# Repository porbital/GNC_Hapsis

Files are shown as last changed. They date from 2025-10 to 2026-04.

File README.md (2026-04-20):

# GNC_Hapsis

Software and hardware for GNC Hapsis.

    If you have any questions, please reach out to Matthew Allen on Slack.

## STAG Software 

The C++ code is stored in `STAG/flight_controller_v3`.

This was developed using PlatformIO, but can be used with Arduino IDE as well.

The current software is complete and will be used on the STAG mission. 

Hardware-in-the-loop is possible with this code setup, and can be enabled by commenting out the flag in `config.h`

## STAG PCB

The PCB for this project (version 4.1) is stored under `polaris4.1/`.

The current PCB is fully complete. I assembled it without a stencil, using solder paste and a hot plate. (In the future, it is worth buying a stencil).

### AI Transparency Statement

As I'm sure you all are aware, AI is an incredibly powerful tool. However, I think that it is important to be honest and clear regarding how it is utilized in a project, especially one of this nature.

AI was used for debugging, research, and some code generation (primarily autocomplete and boilerplate code). It also generated the flight visualization script.

# Go Orbital!

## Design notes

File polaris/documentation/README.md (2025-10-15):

# Purdue Orbital GNC -- Polaris Program Documentation

## Overview
This program controls the attitude of a launch structure using thrusters and an inertial measurement unit (IMU) sensor BNO055. It implements a PID control loop to maintain a desired heading (orientation) and logs telemetry data to an SD card. The program also manages status LEDs and thruster actuation using digital I/O pins.

---

## Hardware Inputs and Pinout

| Name | Pin | Description |
|---|---|---|
| SCL | IMU SCL | I2C clock line for BNO055 IMU |
| SDA | IMU SDA | I2C data line for BNO055 IMU |
| 3.3V | VIN on IMU | Power supply for the IMU |
| D5 | GPIO D5 | Yellow LED (flashes during countdown) |
| D6 | GPIO D6 | Green LED (blinks while running) |
| D9 | GPIO D9 | Red LED (blinks on error/failure) |
| D10 | Thruster L | Left thruster control (not currently used) |
| D11 | Thruster R | Right thruster control (not currently used) |
| D12 | Thruster 3 | Thruster control (connected to positive thruster) |
| D13 | Thruster 4 | Thruster control (connected to negative thruster) |
| GND | Ground | Common ground for LEDs, IMU, and MOSFETs |
| SD Card CS | board.SD_CS| Chip select pin for SD card SPI interface |
| SD Card CLK | board.SD_CLK| SPI clock for SD card |
| SD Card MOSI | board.SD_MOSI| SPI MOSI for SD card |
| SD Card MISO | board.SD_MISO| SPI MISO for SD card |

## Main Power Architecture

The power system starts with a 14.8V battery, which is stepped down to 12V via a buck converter. Each MOSFET board receives switched 12V power and output signals to individual solenoid valves, enabling safe control of thrusters. This modular design allows independent activation of thrusters and easy troubleshooting.

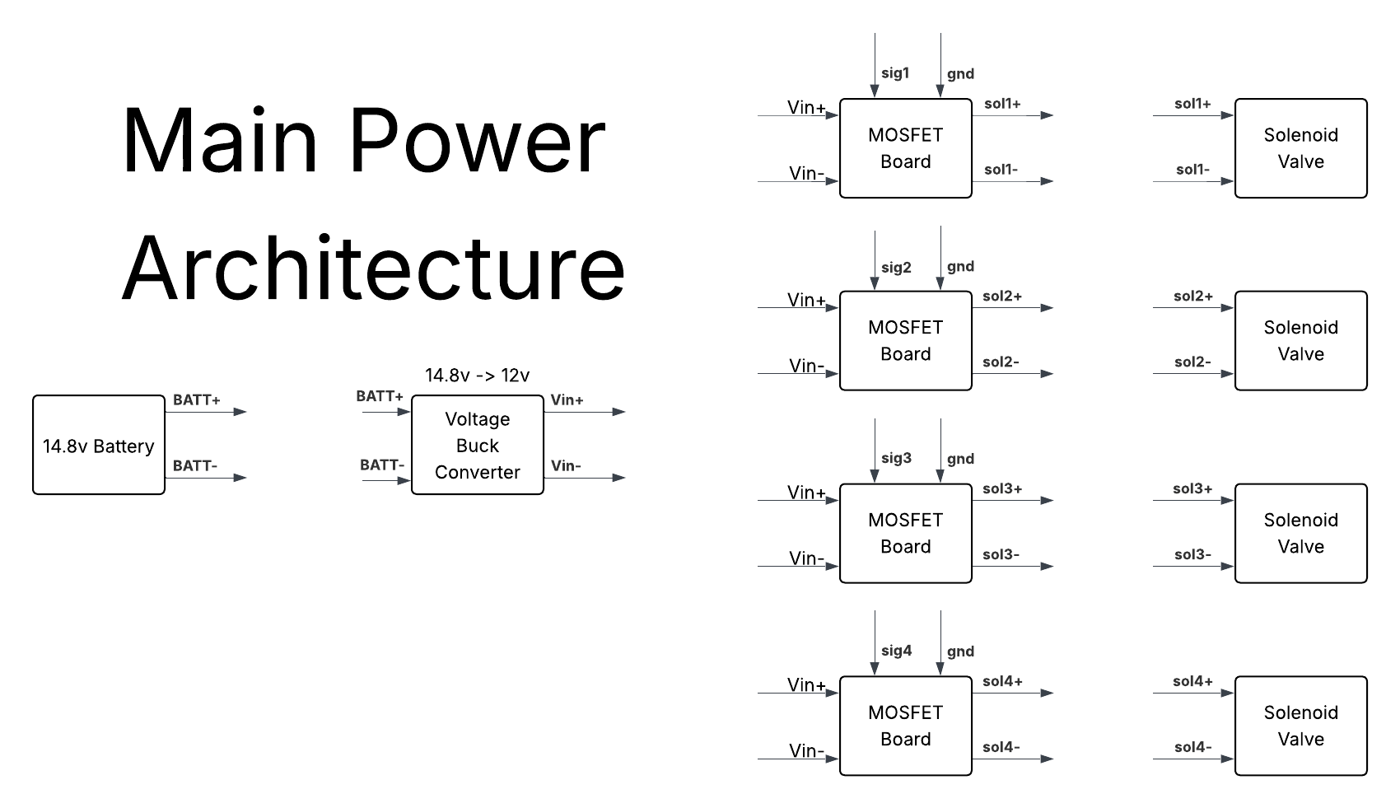
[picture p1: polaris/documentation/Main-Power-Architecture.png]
Main Power Architecture

---

## Flight Software Wiring

This schematic shows how the IMU (BNO055) connects via I2C (SCL, SDA, 3.3V, GND) to the Raspberry Pi RP2040 microcontroller. The RP2040 directs LED status signals and outputs digital thruster control pins (sig1–sig4) to the MOSFET boards, interfacing each with its corresponding solenoid valve. Separate or buck-converted power ensures safe operation of logic and actuators.
:w

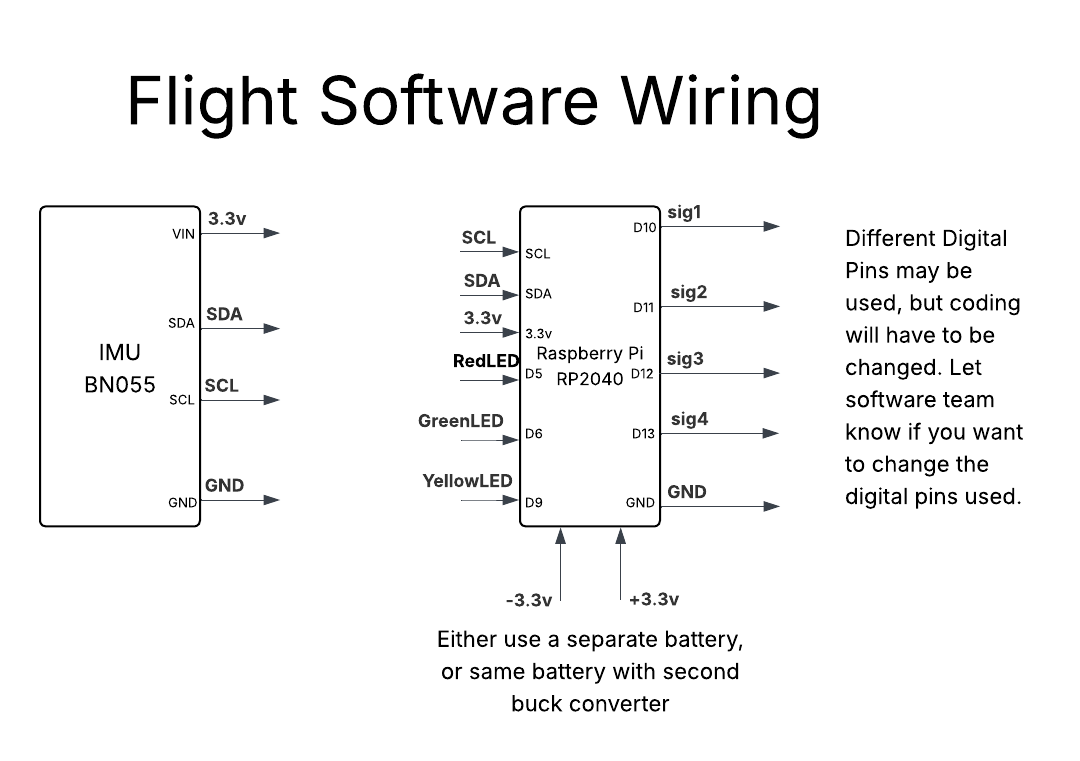
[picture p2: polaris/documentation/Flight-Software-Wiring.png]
Flight Software Wiring


---
**Thruster Notes:**
- Thruster 1 and 3 impart negative torque on the structure.
- Thruster 2 and 4 impart positive torque.
- Current thruster firing only uses left/right thrusters (D12 and D13 pins).
- Thrusters are controlled through MOSFETs connected to these GPIO pins.

---

## Functions

### `temperature()`
Reads and filters the temperature from the BNO055 IMU sensor. Checks for a specific error condition with the sensor and returns a corrected temperature value.

### `get_current_heading()`
Reads the current heading in degrees from the IMU sensor's Euler angle output.

---

## How It Works

### Initialization
- LEDs and thruster control pins are initialized as digital outputs.
- The program performs a 5-step countdown indicated by flashing the yellow LED.
- The SD card is initialized and a new CSV log file is created with a timestamped filename.
- I2C communication is started with the BNO055 IMU sensor.
- Status variables and PID constants are set up.

### Main Control Loop
- The program continuously reads the current heading from the IMU.
- It calculates the error between the desired heading (setpoint = 0°, North) and the current heading, accounting for angle wraparound (handling 0° = 360°).
- Time elapsed between loop iterations is calculated for derivative computations.
- A low-pass filter smooths the derivative of error to reduce noise.
- PID output is computed using proportional (Kp) and derivative (Kd) gains.
- Based on PID output, one of two thrusters is fired to correct the heading:
  - Positive output fires the negative thruster (right)
  - Negative output fires the positive thruster (left)
- A deadzone threshold prevents thrusters from firing for small errors near zero.
- The green LED blinks continuously to indicate the system is active.
- Telemetry data including time delta, angular position, thruster states, gyro data, and PID values are logged to the SD card.
- Errors during operation cause the red LED to blink indefinitely and print error messages.

### PID Control Details
- Proportional gain \(K_p = 0.56\) and derivative gain \(K_d = 0.45\) are tuned constants for controlling the thrusters.
- The derivative is filtered using a low-pass filter with time constant \(\tau = 0.1\) to reduce sensor noise effects.
- Error is calculated with wrap-around so the heading difference is always within \([-180°, 180°]\).

---

## Status LEDs

| LED Color | Pin | Function |
|---|-----|---|
| Red | D9  | Indicates failure/error |
| Green | D6  | Blinks to show the program is running |
| Yellow | D5  | Flashes during countdown before start |

---

## Summary
This software manages an attitude control system with:

- An IMU sensor to read orientation.
- A PID controller to maintain a set heading.
- Thrusters activated through MOSFETs to apply torque.
- Status LEDs to provide feedback on system state.
- Data logging of sensor and control data to an SD card for post-flight analysis.

The implementation focuses on error handling and stable control through filtering and set thresholds in a resource-constrained embedded environment.

---

*Documentation generated for the Purdue Orbital GNC Polaris Program by Adafruit Industries under MIT License.*

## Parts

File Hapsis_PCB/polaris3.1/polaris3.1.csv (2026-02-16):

Id | Designator | Footprint | Quantity | Designation | Supplier and ref
1 | R13 | R_0603_1608Metric | 1 | 10k
2 | Q3,Q2,Q1,Q4 | TO-220-3_Horizontal_TabDown | 4 | IRLB8721PBF
3 | R1,R7,R4,R8 | R_1206_3216Metric | 4 | 150
4 | C6,C4 | C_0805_2012Metric | 2 | 22uF
5 | J4,J3,J2,J5 | TerminalBlock_RND_205-00276_1x02_P5.00mm_Vertical | 4 | Screw_Terminal_01x02
6 | R5,R3,R6,R2 | R_1206_3216Metric | 4 | 10k
7 | U2 | SOT-23-6 | 1 | TPS56339DDC
8 | D4,D5,D1,D3 | D_DO-41_SOD81_P10.16mm_Horizontal | 4 | 1N4007
9 | R14 | R_0603_1608Metric | 1 | 30
10 | CAN TX | PinHeader_1x07_P2.54mm_Vertical | 1 | CAN
11 | D6,D7 | LED_1210_3225Metric | 2 | LED
12 | L1 | L_Bourns_SRP1038C_10.0x10.0mm | 1 | 10uH
13 | R10,R9 | R_1206_3216Metric | 2 | 1.8k
14 | J7 | TerminalBlock_Phoenix_MKDS-1,5-2_1x02_P5.00mm_Horizontal | 1 | Screw_Terminal_01x02
15 | BNO055 IMU | PinHeader_1x06_P2.54mm_Vertical | 1 | Conn_01x06_Socket
16 | C3,C5 | C_0805_2012Metric | 2 | 100nF
17 | C1,C2 | C_0805_2012Metric | 2 | 10uF
18 | R12 | R_0603_1608Metric | 1 | 140k
19 | A1 | Arduino_Nano | 1 | Arduino_Nano_ESP32

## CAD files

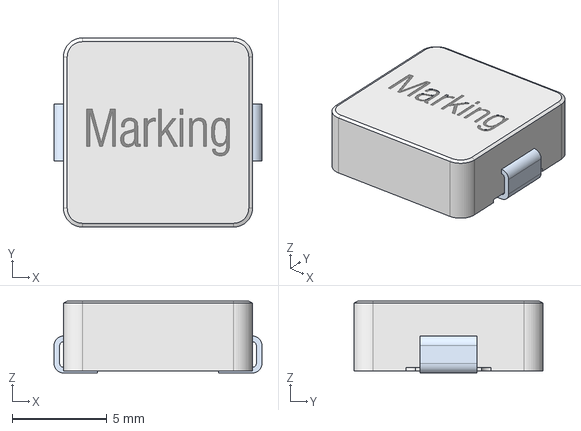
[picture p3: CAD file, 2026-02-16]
Hapsis_PCB/polaris3.1/vendor_files/WE-LHMI_1040+(rev1).stp
11.0 x 10.0 x 3.80 mm

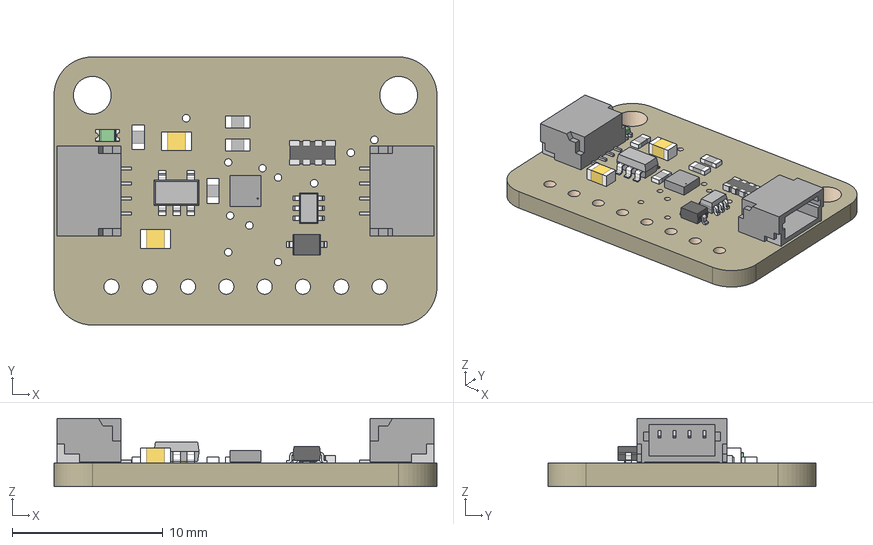
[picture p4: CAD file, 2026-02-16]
Hapsis_PCB/polaris4.1/vendor_files/4816 BMP390 QT.step
25.4 x 17.8 x 4.53 mm
Board
10K x 4
1N4148
BMP388
10uF x 2
AP2112K-3.3
10K_1
BSS138
STEMMA_I2C_QT x 2
GREEN

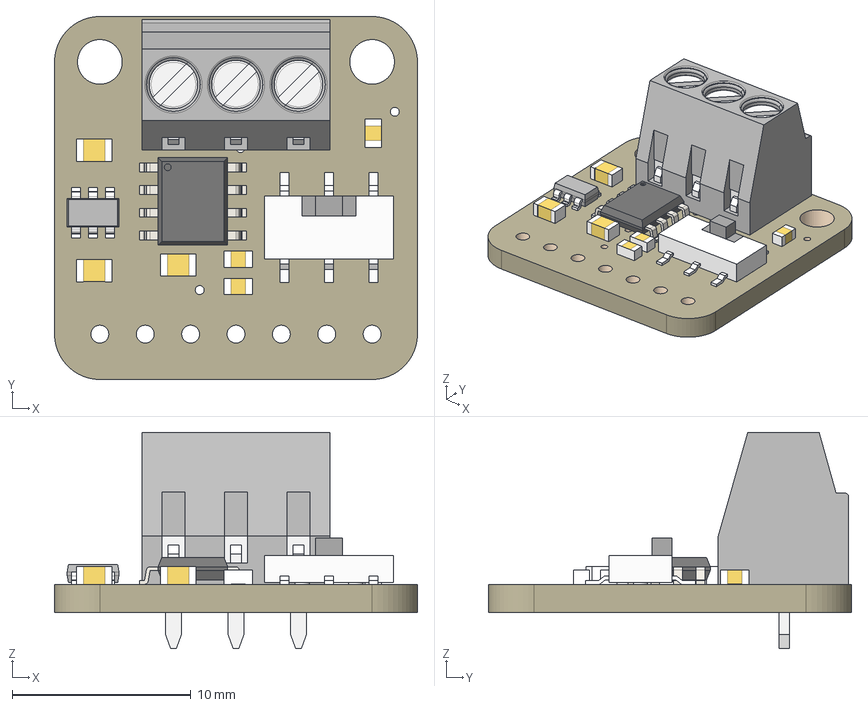
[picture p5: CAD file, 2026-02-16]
Hapsis_PCB/polaris3.1/vendor_files/5708 CAN Pal.step
20.3 x 20.3 x 12.1 mm
Board
TJA1051T/3
3.5mm Terminal
10uF x 2
AP3602
1uF
60 ohm x 3
EG1390

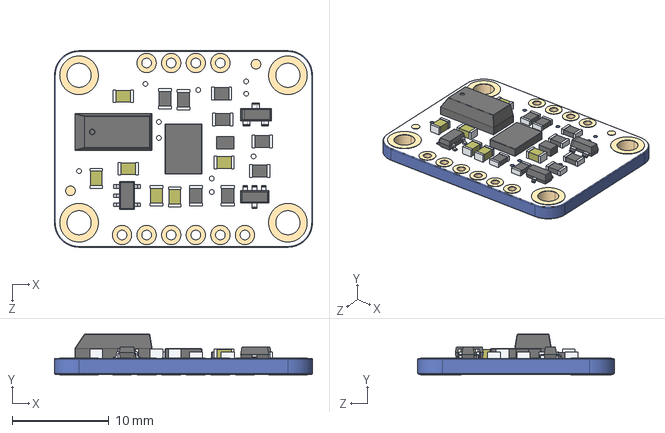
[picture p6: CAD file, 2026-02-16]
Hapsis_PCB/polaris4.1/vendor_files/Adafruit_BNO055_AP214.STEP
26.7 x 4.20 x 20.3 mm

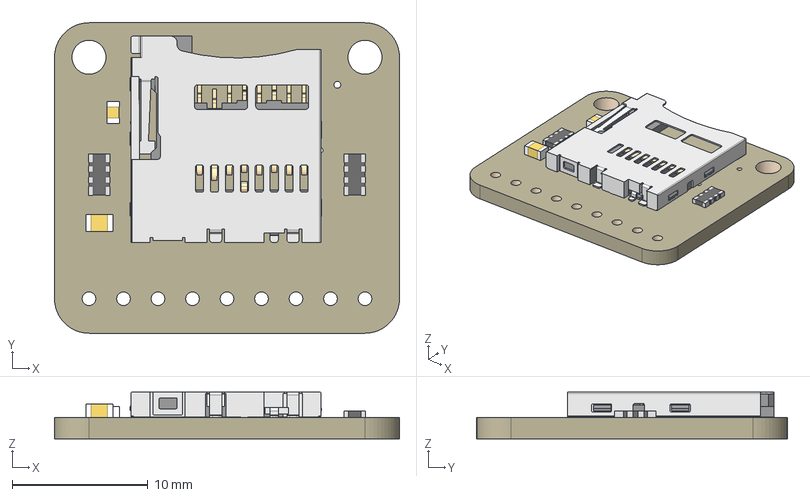
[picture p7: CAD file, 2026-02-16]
Hapsis_PCB/polaris3.1/vendor_files/4682 Micro SD Breakout.step
25.4 x 22.9 x 3.45 mm
Board
microSD
10uF
0.1uF
47K x 2

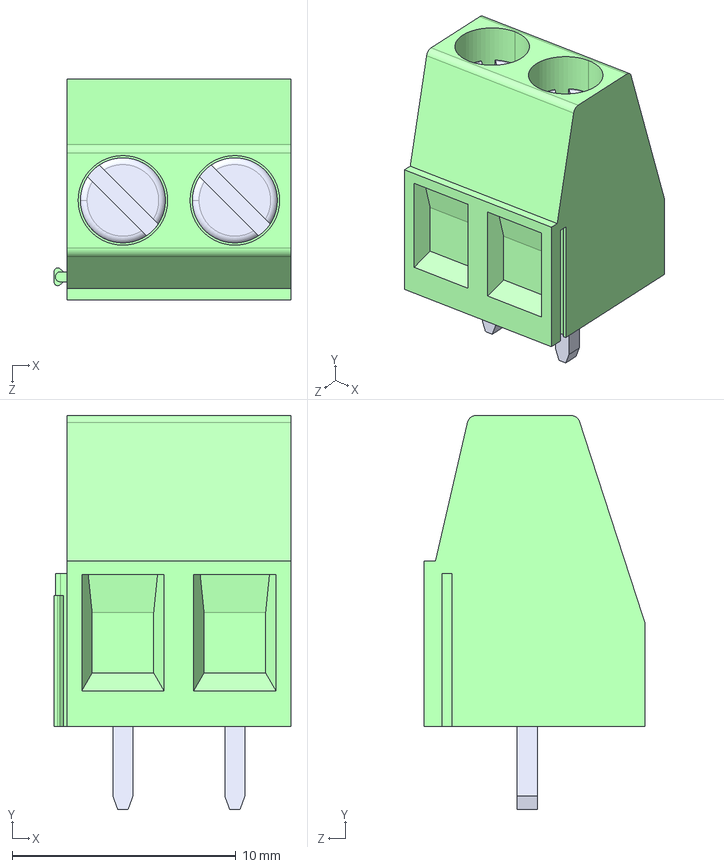
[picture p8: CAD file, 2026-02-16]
Hapsis_PCB/polaris3.1/vendor_files/SCREW_TERMINAL.STEP
10.6 x 17.6 x 9.85 mm
Pin^1715xxx x 2
Screw^1715xxx x 2

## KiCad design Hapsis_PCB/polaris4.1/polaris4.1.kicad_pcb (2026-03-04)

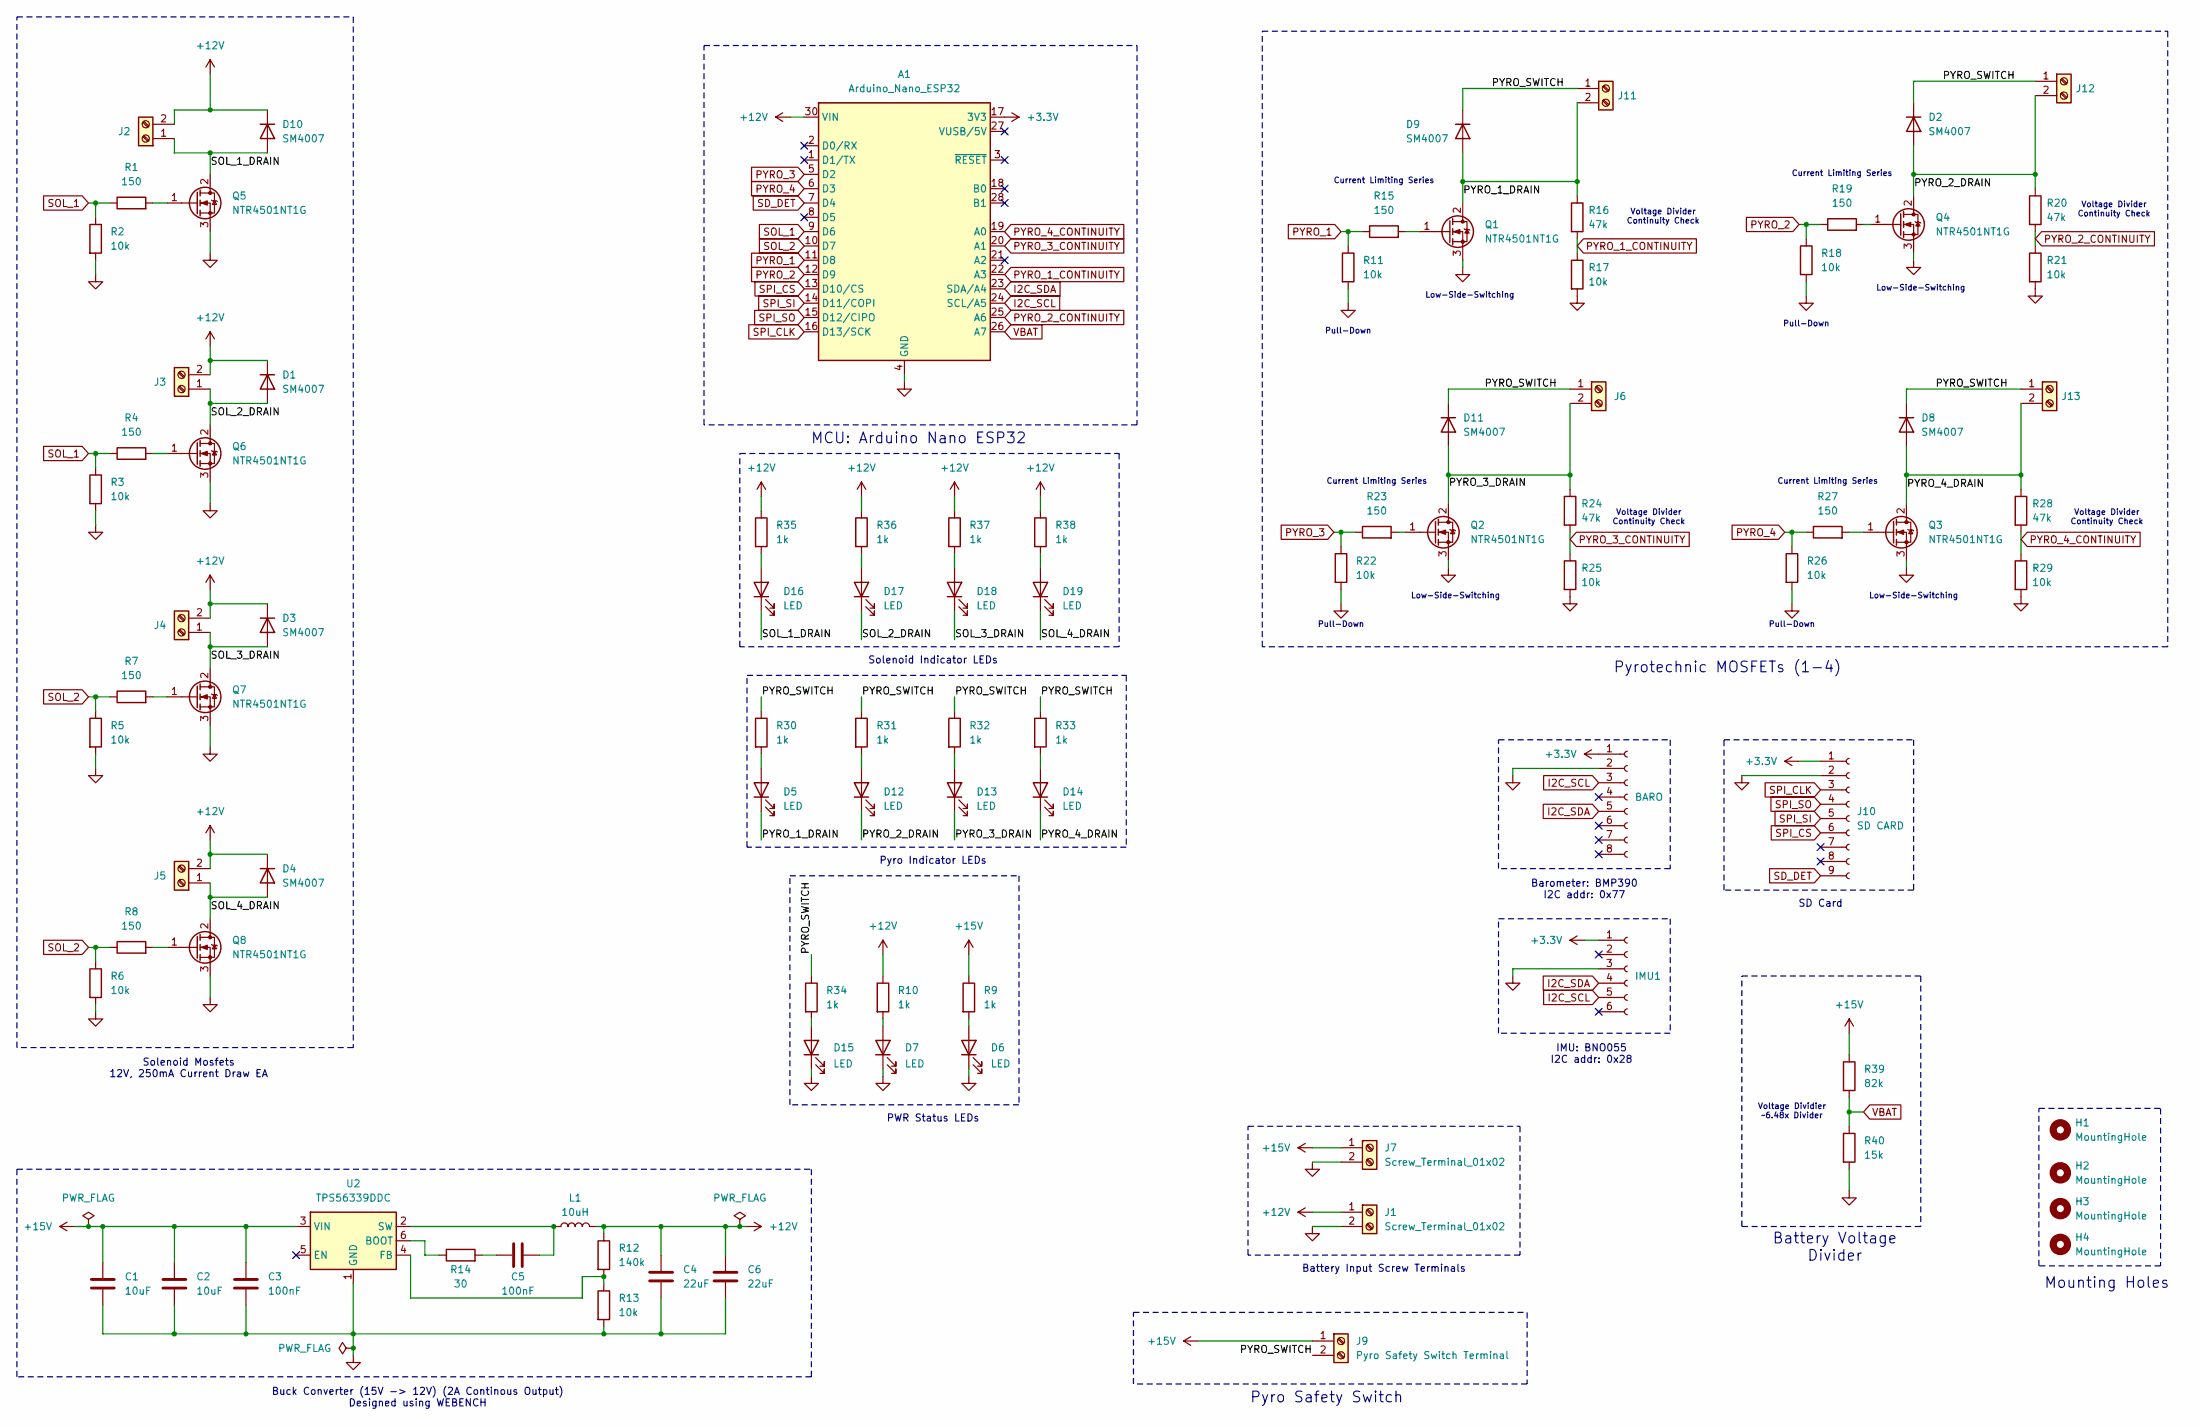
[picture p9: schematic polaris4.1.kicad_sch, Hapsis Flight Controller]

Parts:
A1: Arduino_Nano_ESP32; Arduino_Nano
C1, C2: 10uF; C_0805_2012Metric
C3, C5: 100nF; C_0805_2012Metric
C4, C6: 22uF; C_0805_2012Metric
D1, D2, D3, D4, D8, D9, D10, D11: SM4007; D_MELF
D5, D6, D7, D12, D13, D14, D15, D16, D17, D18, D19: LED; LED_0603_1608Metric
H1, H2, H3, H4: MountingHole; MountingHole_3mm
IMU1: Conn_01x06_Socket; PinHeader_1x06_P2.54mm_Vertical
J1, J7: Screw_Terminal_01x02; TerminalBlock_Phoenix_MKDS-1,5-2_1x02_P5.00mm_Horizontal
J2, J3, J4, J5, J6, J11, J12, J13: Screw_Terminal_01x02; TerminalBlock_RND_205-00276_1x02_P5.00mm_Vertical
J8: BARO; PinHeader_1x08_P2.54mm_Vertical
J9: Pyro Safety Switch Terminal; TerminalBlock_Phoenix_MKDS-1,5-2_1x02_P5.00mm_Horizontal
J10: SD CARD; PinHeader_1x09_P2.54mm_Vertical
L1: 10uH; L_Bourns_SRP1038C_10.0x10.0mm
Q1, Q2, Q3, Q4, Q5, Q6, Q7, Q8: NTR4501NT1G; SOT-23-3
R1, R4, R7, R8, R15, R19, R23, R27: 150; R_0805_2012Metric
R2, R3, R5, R6, R11, R17, R18, R21, R22, R25, R26, R29: 10k; R_0805_2012Metric
R9, R10, R30, R31, R32, R33, R34, R35, R36, R37, R38: 1k; R_0805_2012Metric
R12: 140k; R_0603_1608Metric
R13: 10k; R_0603_1608Metric
R14: 30; R_0603_1608Metric
R16, R20, R24, R28: 47k; R_0805_2012Metric
R39: 82k; R_0805_2012Metric
R40: 15k; R_0805_2012Metric
U2: TPS56339DDC; SOT-23-6

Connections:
+3.3V: A1.17 (3V3), IMU1.1, J8.1, J10.1
+12V: A1.30 (VIN), C4.1, C6.1, D1.1 (K), D3.1 (K), D4.1 (K), D10.1 (K), J1.1, J2.2, J3.2, J4.2, J5.2, L1.2, R10.1, R12.1, R35.1, R36.1, R37.1, R38.1
+15V: C1.1, C2.1, C3.1, J7.1, J9.1, R9.1, R39.1, U2.3 (VIN)
/PYRO_1_DRAIN: D5.1 (K), D9.2 (A), J11.2, Q1.2 (D), R16.1
/PYRO_2_DRAIN: D2.2 (A), D12.1 (K), J12.2, Q4.2 (D), R20.1
/PYRO_3_DRAIN: D11.2 (A), D13.1 (K), J6.2, Q2.2 (D), R24.1
/PYRO_4_DRAIN: D8.2 (A), D14.1 (K), J13.2, Q3.2 (D), R28.1
/PYRO_SWITCH: D2.1 (K), D8.1 (K), D9.1 (K), D11.1 (K), J6.1, J9.2, J11.1, J12.1, J13.1, R30.1, R31.1, R32.1, R33.1, R34.1
/SOL_1_DRAIN: D10.2 (A), D16.1 (K), J2.1, Q5.2 (D)
/SOL_2_DRAIN: D1.2 (A), D17.1 (K), J3.1, Q6.2 (D)
/SOL_3_DRAIN: D3.2 (A), D18.1 (K), J4.1, Q7.2 (D)
/SOL_4_DRAIN: D4.2 (A), D19.1 (K), J5.1, Q8.2 (D)
GND: A1.4 (GND), A1.29 (GND), C1.2, C2.2, C3.2, C4.2, C6.2, D6.1 (K), D7.1 (K), D15.1 (K), IMU1.3, J1.2, J7.2, J8.2, J10.2, Q1.3 (S), Q2.3 (S), Q3.3 (S), Q4.3 (S), Q5.3 (S), Q6.3 (S), Q7.3 (S), Q8.3 (S), R2.2, R3.2, R5.2, R6.2, R11.2, R13.2, R17.2, R18.2, R21.2, R22.2, R25.2, R26.2, R29.2, R40.2, U2.1 (GND)
I2C_SCL: A1.24 (SCL/A5), IMU1.5, J8.3
I2C_SDA: A1.23 (SDA/A4), IMU1.4, J8.5
unnamed: C5.2, R14.2
unnamed: D5.2 (A), R30.2
unnamed: D6.2 (A), R9.2
unnamed: D7.2 (A), R10.2
unnamed: D12.2 (A), R31.2
unnamed: D13.2 (A), R32.2
unnamed: D14.2 (A), R33.2
unnamed: D15.2 (A), R34.2
unnamed: D16.2 (A), R35.2
unnamed: D17.2 (A), R36.2
unnamed: D18.2 (A), R37.2
unnamed: D19.2 (A), R38.2
unnamed: Q1.1 (G), R15.2
unnamed: Q2.1 (G), R23.2
unnamed: Q3.1 (G), R27.2
unnamed: Q4.1 (G), R19.2
unnamed: Q5.1 (G), R1.2
unnamed: Q6.1 (G), R4.2
unnamed: Q7.1 (G), R7.2
unnamed: Q8.1 (G), R8.2
unnamed: R14.1, U2.6 (BOOT)
unnamed: R12.2, R13.1, U2.4 (FB)
unnamed: C5.1, L1.1, U2.2 (SW)
PYRO_1: A1.11 (D8), R11.1, R15.1
PYRO_1_CONTINUITY: A1.22 (A3), R16.2, R17.1
PYRO_2: A1.12 (D9), R18.1, R19.1
PYRO_2_CONTINUITY: A1.25 (A6), R20.2, R21.1
PYRO_3: A1.5 (D2), R22.1, R23.1
PYRO_3_CONTINUITY: A1.20 (A1), R24.2, R25.1
PYRO_4: A1.6 (D3), R26.1, R27.1
PYRO_4_CONTINUITY: A1.19 (A0), R28.2, R29.1
SD_DET: A1.7 (D4), J10.9
SOL_1: A1.9 (D6), R1.1, R2.1, R3.1, R4.1
SOL_2: A1.10 (D7), R5.1, R6.1, R7.1, R8.1
SPI_CLK: A1.16 (D13/SCK), J10.3
SPI_CS: A1.13 (D10/CS), J10.6
SPI_SI: A1.14 (D11/COPI), J10.5
SPI_SO: A1.15 (D12/CIPO), J10.4
VBAT: A1.26 (A7), R39.2, R40.1

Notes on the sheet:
Pyro Safety Switch
Low-Side-Switching
Voltage Divider Continuity Check
Barometer: BMP390 I2C addr: 0x77
Current Limiting Series
Solenoid Indicator LEDs
SD Card
Battery Voltage Divider
Pull-Down
Pyrotechnic MOSFETs (1-4)
Battery Input Screw Terminals
Buck Converter (15V -> 12V) (2A Continous Output) Designed using WEBENCH
Mounting Holes
MCU: Arduino Nano ESP32
IMU: BNO055 I2C addr: 0x28
Voltage Dividier ~6.48x Divider
PWR Status LEDs
Solenoid Mosfets 12V, 250mA Current Draw EA
Pyro Indicator LEDs

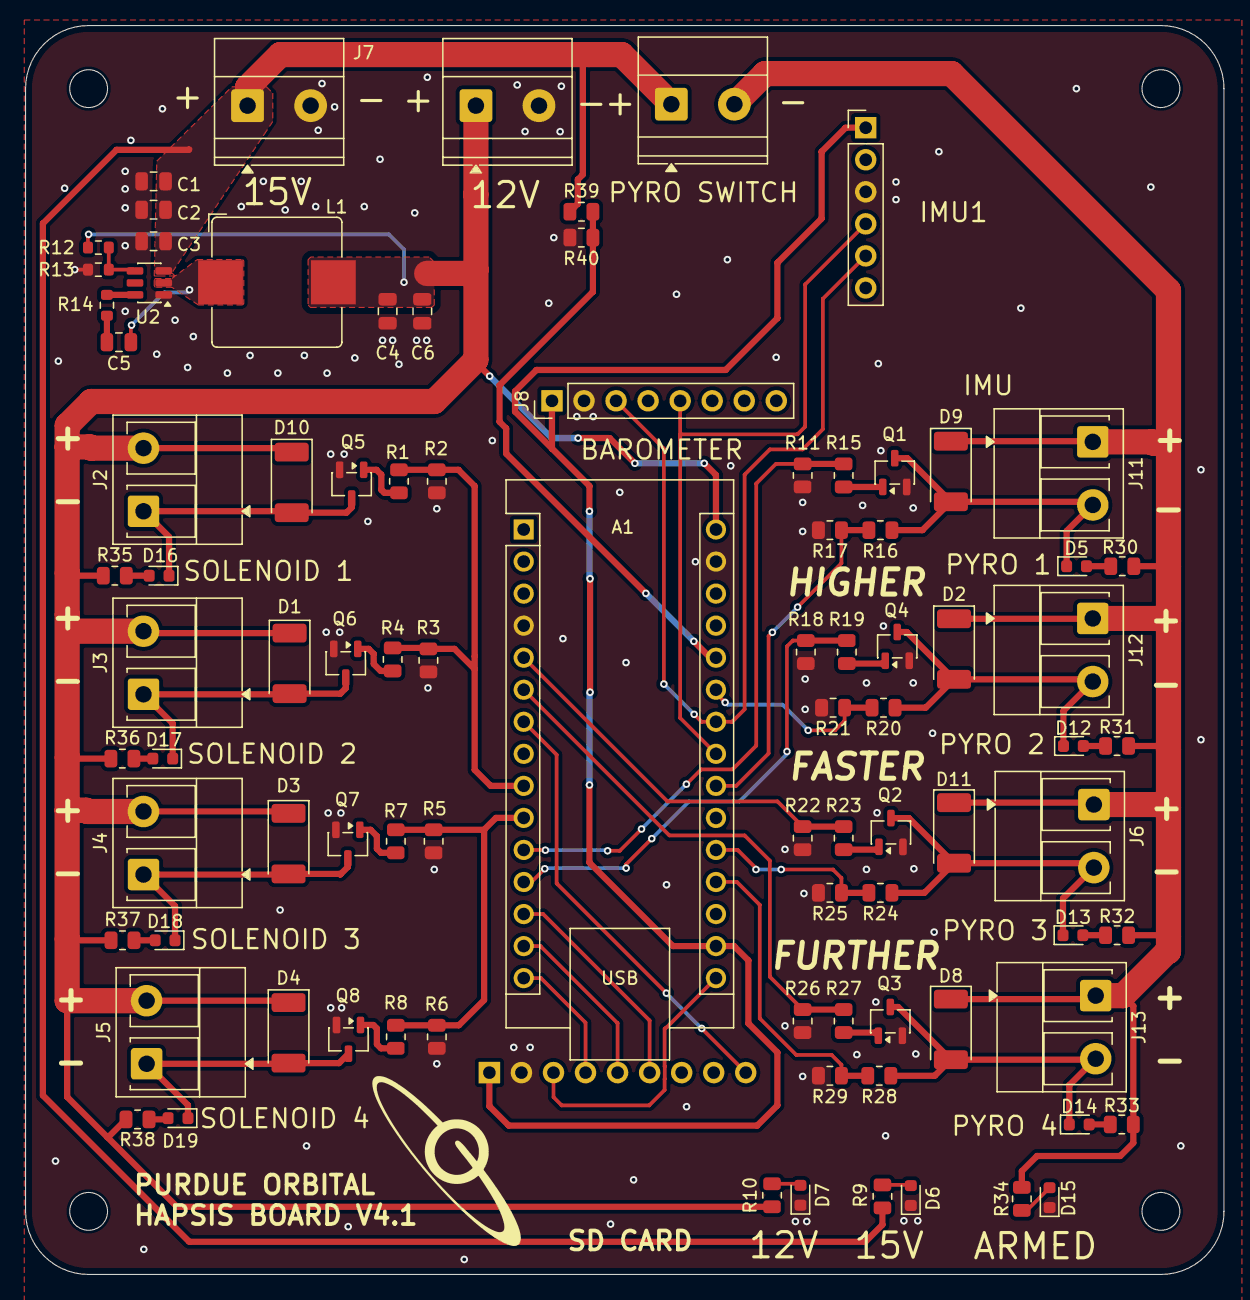
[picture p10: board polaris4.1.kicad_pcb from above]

Board: 2 copper layers, 95.0 x 99.0 mm, 94 parts (1 on the bottom side), 54 nets.

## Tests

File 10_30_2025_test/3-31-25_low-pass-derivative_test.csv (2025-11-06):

Time | Angular Position | R Solenoid | L Solenoid | Angular Vel X | Angular Vel Y | Angular Vel Z | PID Error | P | D
4.075 | 0.0 | 0 | 0 | -0.00109083 | -0.00654499 | -0.00109083 | 0.0 | 0.0 | 0.0
0.0609989 | 0.0 | 0 | 0 | -0.00109083 | -0.00654499 | 0.00109083 | 0.0 | 0.0 | 0.0
0.0620003 | 359.938 | 0 | 0 | -0.00109083 | -0.00545416 | 0.00109083 | 0.208611 | 1.00806 | 0.385802
0.107 | 359.938 | 0 | 0 | -0.00327249 | -0.00545416 | -0.00109083 | 0.11887 | 0.0 | 0.186377
0.0620003 | 359.938 | 0 | 0 | 0.00218166 | -0.00545416 | 0.0 | 0.0867713 | 0.0 | 0.115047
0.0609989 | 359.938 | 0 | 0 | -0.00218166 | -0.00545416 | 0.0 | 0.0671563 | 0.0 | 0.0714585
0.0670013 | 359.938 | 0 | 0 | -0.00218166 | -0.00436333 | 0.0 | 0.0542551 | 0.0 | 0.0427892
0.0609989 | 359.938 | 0 | 0 | -0.00109083 | -0.00218166 | 0.00109083 | 0.0469598 | 0.0 | 0.0265773
0.0620003 | 359.938 | 0 | 0 | -0.00109083 | -0.00545416 | 0.0 | 0.0423826 | 0.0 | 0.0164057
0.0599995 | 359.938 | 0 | 0 | 0.00109083 | -0.00981748 | -0.00109083 | 0.0396141 | 0.0 | 0.0102536
0.0610008 | 359.938 | 0 | 0 | 0.0 | 0.00109083 | 0.00109083 | 0.0378659 | 0.0 | 0.00636866
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

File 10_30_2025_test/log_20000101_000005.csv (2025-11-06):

Time | Angular Position | R Solenoid | L Solenoid | Angular Vel X | Angular Vel Y | Angular Vel Z | PID Error | P | D
3.559 | 0.0 | 0 | 0 | -0.00218166 | -0.00763582 | 0.00109083 | 0.0 | 0.0 | 0.0
0.0569992 | 360.0 | 0 | 0 | -0.00218166 | -0.00763582 | 0.0 | 0.0 | 0.0 | 0.0
0.0550003 | 360.0 | 0 | 0 | -0.00327249 | -0.00436333 | 0.0 | 0.0 | 0.0 | 0.0
0.0550003 | 360.0 | 0 | 0 | -0.00109083 | -0.00436333 | 0.00109083 | 0.0 | 0.0 | 0.0
0.101999 | 360.0 | 0 | 0 | -0.00109083 | -0.00436333 | 0.0 | 0.0 | 0.0 | 0.0
0.0570011 | 360.0 | 0 | 0 | -0.00545416 | -0.00327249 | -0.00109083 | 0.0 | 0.0 | 0.0
0.105 | 360.0 | 0 | 0 | 0.00327249 | -0.00218166 | 0.00109083 | 0.0 | 0.0 | 0.0
0.0620003 | 360.0 | 0 | 0 | 0.0 | -0.00327249 | 0.0 | 0.0 | 0.0 | 0.0
0.0559998 | 360.0 | 0 | 0 | 0.0 | -0.00436333 | 0.0 | 0.0 | 0.0 | 0.0
0.0569992 | 359.938 | 0 | 0 | -0.00109083 | -0.00327249 | -0.00109083 | 0.528428 | 0.0625 | 1.09651
0.0550003 | 359.938 | 0 | 0 | -0.00109083 | 0.00109083 | 0.0 | 0.035 | 0.0625 | 0.0
0.0559998 | 359.938 | 0 | 0 | 0.00218166 | -0.00218166 | 0.00109083 | 0.035 | 0.0625 | 0.0
0.0580006 | 359.938 | 0 | 0 | -0.00218166 | -0.00109083 | -0.00109083 | 0.035 | 0.0625 | 0.0
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

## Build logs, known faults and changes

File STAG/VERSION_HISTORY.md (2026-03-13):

# Version History

## Hapsis Flight Controller Code

### Most up-to date is V2, stored in `flight_controller_v2`

#### V1 `/flight_controller`

First iteration, uploaded Feb 19, 2026. This version added the basic foundation for the program, including the state machine, web server, etc.

It is missing the sensor code and the GNC implmentation.

#### V2 `/flight_controller_v2`

Uploaded Mar 13, 2026. This version added a lot of functionality, including the sensor code, data logging, and also a python script for data analysis. 

Thank you to Alayna and Michael for helping with the sensor code!

Flight visualization script is stored under `GNC_HAPSIS/STAG/data_analysis`

-- Matt

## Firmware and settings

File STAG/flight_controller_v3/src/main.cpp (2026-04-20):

#include "Config.h"
#include "PID.h"
#include "Actuators.h"
#include "Logging.h"
#include "Sensors.h"
#include "MissionState.h"
#include "MissionWebServer.h"

PIDController pid(PID_KP, PID_KD, PID_KI);

unsigned long lastLoopTime = 0;
unsigned long lastLogTime = 0;



// Function prototypes
void checkLiftoff();
void checkGNCActivation(float altitude, float acceleration);
void checkPyroTrigger();
void checkDescent(float altitude);
void checkLanding(float altitude, float vertical_vel);
float getVerticalVelocity(float altitude);

void setup() {
  Serial.begin(115200);
  delay(10000);
  Serial.println("=== Hapsis Payload System ===");

  initSensors();
  initActuators();
  initLogging();

  initWebServer();


  pid.setSetpoint(HEADING);

  // Ensure ground state on startup
  transitionToState(GROUND);
}

void loop() {

  handleWebServer();

  unsigned long currentTime = millis();

  // Consistent 100Hz loop for state management and control
  // Non-blocking
  if (currentTime >= lastLoopTime + LOOP_PERIOD) {
    unsigned long deltaMs = currentTime - lastLoopTime;
    lastLoopTime = currentTime;
    float deltaT = deltaMs / 1000.0; 

    // Read sensor data
    float temperature, pressure, altitude;
    float roll, pitch, heading, vertical_accel, vertical_vel;
    
    readBarometer(temperature, pressure, altitude);
    readIMU(roll, pitch, heading, vertical_accel);

    // Estimate vertical velocity
    vertical_vel = getVerticalVelocity(altitude);

    // Update web server data
    setWebAltitude(altitude);
    setWebVerticalVelocity(vertical_vel);

    // Log data
    if (currentTime >= lastLogTime + LOG_PERIOD) {
      logData(currentTime, temperature, pressure,
         altitude, roll, pitch, heading, vertical_accel, vertical_vel,
          getLeftThrusterState(), getRightThrusterState(), currentState);
      lastLogTime = currentTime;
    }


    // State machine
    switch(currentState) {
      case GROUND:
      // Wait for ARM command via web or serial
        if (Serial.available() > 0) {
          String command = Serial.readStringUntil('\n');
          command.trim();
          if (command.equalsIgnoreCase("ARM")) {
            transitionToState(ARMED);
          }
        }
        break;

      case ARMED:
        // Wait for LAUNCH command via web or serial
        if (Serial.available() > 0) {
          String command = Serial.readStringUntil('\n');
          command.trim();
          if (command.equalsIgnoreCase("LAUNCH")) {
            transitionToState(ASCENT);
          } else if (command.equalsIgnoreCase("ABORT")) {
            transitionToState(GROUND);
          }
        }
        break;

      case ASCENT:

        // If time since launch > MAX_ASCENT_TIME, turn on GNC as backup
        if (currentTime - stateStartTime >= ABORT_FIRE_PYRO_TIME) {
          gncStartTime = millis();
          transitionToState(GNC_ACTIVE);
        }

        checkGNCActivation(altitude, vertical_vel);
        break;

      case GNC_ACTIVE:
      {
        if (currentTime - gncStartTime >= GNC_TIME) { // Give GNC 30 seconds 
          disableAllActuators(); // Ensure thrusters are off
          transitionToState(PYRO_FIRED);
        }
        // Start PID controller
        float pidOutput = pid.compute(heading, deltaT);

        // Print PID output and heading, pitch, roll for debugging
        Serial.println("PID Output: " + String(pidOutput) + " | Heading: " + String(heading) + " | Pitch: " + String(pitch) + " | Roll: " + String(roll));
        controlThrusters(pidOutput);

        // checkPyroTrigger();
        break;
      }

      case PYRO_FIRED:
        if (firePyros(vertical_vel)) {
          // Pyro sequence completed successfully
          transitionToState(DESCENT);
        }
        break;
      case DESCENT:
         checkLanding(altitude, vertical_vel);
         break;
      case LANDED:
        break;
    }
  }
}
  


void checkLiftoff() {
  // Based on altitude and acceleration thresholds 
}

// If altitude > threshold and vertical velocity > threshold, transition to GNC_ACTIVE
void checkGNCActivation(float altitude, float verticalVelocity) {
  if (altitude > TARGET_ALTITUDE && verticalVelocity > GNC_ACTIVATION_VELOCITY) {
    transitionToState(GNC_ACTIVE);
    gncStartTime = millis();
  }
}

void checkPyroTrigger() {
  // Based on heading error and hold time
  // if (headingReached(currentHeading, HEADING)) {
  //   firePyros();
  //   transitionToState(PYRO_FIRED);
  // }
}

// If vertical velocity < threshold, transition to DESCENT
void checkDescent(float vertical_vel) {
  if (vertical_vel < DESCENT_VELOCITY_THRESHOLD)  {
    transitionToState(DESCENT);
  }

}

// If altitude < threshold and vertical velocity < threshold, transition to LANDED
// Slight bufffer on velocity to account for noise (velocity +- 0.5 m/s)
void checkLanding(float altitude, float vertical_vel) {
  if (altitude < ALTITUDE_LANDING_THRESHOLD && 
      abs(vertical_vel) < LANDING_VELOCITY_THRESHOLD) {
    transitionToState(LANDED);
  }
}

float getVerticalVelocity(float altitude) {
  // Implement a simple velocity estimator based on altitude changes
  static float lastAltitude = 0;
  static unsigned long lastTime = 0;
  static float filteredVelocity = 0;
  static bool firstRun = true;

  unsigned long currentTime = millis();

  if (lastTime > 0) {
    float deltaT = (currentTime - lastTime) / 1000.0; // Convert ms to seconds
    
    // Ensure deltaT is positive to avoid division by zero or negative velocity
    if (deltaT > 0) {
      float rawVelocity = (altitude - lastAltitude) / deltaT; // m/s
      
      // EMA Low Pass Filter with tau = 0.05
      float tau = 0.75;
      float alpha = deltaT / (tau + deltaT);
      
      if (firstRun) {
        filteredVelocity = rawVelocity;
        firstRun = false;
      } else {
        filteredVelocity = (alpha * rawVelocity) + ((1.0 - alpha) * filteredVelocity);
      }
    }
  }

  lastAltitude = altitude;
  lastTime = currentTime;

  return filteredVelocity;
}

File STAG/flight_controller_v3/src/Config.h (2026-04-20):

#ifndef CONFIG_H
#define CONFIG_H

#include <Arduino.h>

/* PIN DEFINITIONS */

// Thruster Control Pins
#define THRUSTER_LEFT  6  // Positive torque
#define THRUSTER_RIGHT 7  // Negative torque

// Pyro Control Pins
#define PYRO_DETATCH_1 8 
#define PYRO_DETATCH_2 9 
#define PYRO_POP       2 

/* TIMING */
#define LOOP_PERIOD 10 // 100Hz Loop
#define LOG_PERIOD  100 // 10Hz Logging 
#define MIN_THRUSTER_PULSE 50 // Minimum thruster pulse duration in ms
#define ABORT_FIRE_PYRO_TIME 10000 // Time after which to fire pyro if GNC fails (ms) - 10 minutes

/* PID CONFIG */
#define PID_KP 1.0
#define PID_KI 0.0
#define PID_KD 0.6

#define THRESHOLD_ON 5.0 // Control Effort needed to turn on thrusters
#define THRESHOLD_OFF 2.0 // Control Effort needed to turn off thrusters 
#define MIN_THRUSTER_PULSE 50 // Minimum thruster pulse duration in ms


/* GNC CONFIG */
#define HEADING 0 // Desired heading in degrees
#define HEADING_THRESHOLD 5 // Degrees of error allowed 
#define HEADING_HOLD_TIME 3000 // Time that GNC must be withing heading threshold to trigger pyro (ms)
#define GNC_TIME 30000 // Maximum time to stay in GNC_ACTIVE state before transitioning to PYRO_FIRED (ms) - 30 seconds


#define TARGET_ALTITUDE 250 // Altitude to trigger GNC activation (meters) 1524 meters = 5000 feet
/* 5000 feet */
#define GNC_ACTIVATION_VELOCITY 1.0 // Vertical velocity threshold to trigger GNC (m/s)


/* DESCENT & LANDING CONFIG */
#define DESCENT_VELOCITY_THRESHOLD -0.5   // Vertical velocity threshold to trigger descent state (m/s)
#define LANDING_VELOCITY_THRESHOLD  0.1 // Vertical velocity threshold to trigger landing (m/s)
#define ALTITUDE_LANDING_THRESHOLD 50 // Altitude threshold to trigger landing (meters)


/* HARDWARE IN THE LOOP SHIM*/
// MAKE SURE TO COMMENT OUT BEFORE FLIGHT
//#define HIL_MODE


#endif

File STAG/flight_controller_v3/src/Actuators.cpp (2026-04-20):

// Actuators -- Thruster and pyro control

#include "Actuators.h"

static bool leftThrusterOn = false;
static bool rightThrusterOn = false;
static bool pyroFiring = false;
static unsigned long pyroStartTime = 0;
static unsigned long thrusterOnTime = 0;
unsigned long headingHoldStartTime = 0;
static int pyroSequenceStep = 0;

void initActuators() {
  // Configure thruster pins
  pinMode(THRUSTER_LEFT, OUTPUT);
  pinMode(THRUSTER_RIGHT, OUTPUT);
  
  // Configure pyro pins
  pinMode(PYRO_DETATCH_1, OUTPUT);
  pinMode(PYRO_DETATCH_2, OUTPUT);
  pinMode(PYRO_POP, OUTPUT);
  
  // Ensure all outputs are off
  disableAllActuators();
  
  Serial.println("Thrusters and Pyro initialized");
}

bool headingReached(float currentHeading, float targetHeading) {
  // Check if current heading is within a certain threshold of target
  // AND is holding there for 3 seconds

  if (abs(currentHeading - targetHeading) < HEADING_THRESHOLD) {
    if (headingHoldStartTime == 0) {
      headingHoldStartTime = millis();
    } else if (millis() - headingHoldStartTime >= HEADING_HOLD_TIME) {
      return true; // Heading reached and held
    }
  } else {
    headingHoldStartTime = 0; // Reset timer if we deviate
  }
  return false;
  // NEED TO CHANGE
}

void controlThrusters(float controlEffort) {
  unsigned long currentTime = millis();

  // If a thruster is currently on AND the minimum pulse time hasn't elapsed, 
  // return immediately.
  if ((leftThrusterOn || rightThrusterOn) && 
      (currentTime - thrusterOnTime < MIN_THRUSTER_PULSE)) {
    return;
  }
  
  // Turn ON when effort exceeds the high threshold.
  if (controlEffort > THRESHOLD_ON) {
    // Fire LEFT thruster (positive torque)
    if (!leftThrusterOn) {
      digitalWrite(THRUSTER_LEFT, HIGH);
      digitalWrite(THRUSTER_RIGHT, LOW);
      leftThrusterOn = true;
      rightThrusterOn = false;
      thrusterOnTime = currentTime;
    }
  } 
  else if (controlEffort < -THRESHOLD_ON) {
    // Fire RIGHT thruster (negative torque)
    if (!rightThrusterOn) {
      digitalWrite(THRUSTER_LEFT, LOW);
      digitalWrite(THRUSTER_RIGHT, HIGH);
      leftThrusterOn = false;
      rightThrusterOn = true;
      thrusterOnTime = currentTime;
    }
  } 
  // Turn OFF only when effort drops below the low threshold.
  else if (abs(controlEffort) < THRESHOLD_OFF) {
    if (leftThrusterOn || rightThrusterOn) {
      digitalWrite(THRUSTER_LEFT, LOW);
      digitalWrite(THRUSTER_RIGHT, LOW);
      leftThrusterOn = false;
      rightThrusterOn = false;
    }
  }
  
}


/*
  Event Order:
  -> Fire PYRO_DETACH_2 (middle charge)
  -> Wait 5 seconds
  -> Is velocity negative? If yes, transition to DESCENT
  -> If not, Fire PYRO_DETACH_1
  -> Wait 5 seconds
  -> Is velocity negative? If yes, transition to DESCENT
  -> If not, Fire PYRO_POP
  -> Wait 5 seconds
  -> Is velocity negative? If yes, transition to DESCENT
*/
bool firePyros(float vertical_vel) {
  unsigned long currentTime = millis();

  if (!pyroFiring) {
    Serial.println("FIRING PYRO 2");
    digitalWrite(PYRO_DETATCH_2, HIGH);
    pyroFiring = true;
    pyroStartTime = currentTime;
    pyroSequenceStep = 1;
  }

  if (pyroSequenceStep == 1 && (currentTime - pyroStartTime >= 5000)) {
    digitalWrite(PYRO_DETATCH_2, LOW);
    if (vertical_vel < -1) {
      pyroSequenceStep = 4;
    } else {
      Serial.println("FIRING PYRO 1!");
      digitalWrite(PYRO_DETATCH_1, HIGH);
      pyroStartTime = currentTime;
      pyroSequenceStep = 2;
    }
  }
else if (pyroSequenceStep == 2 && (currentTime - pyroStartTime >= 5000)) {
    digitalWrite(PYRO_DETATCH_1, LOW);
    if (vertical_vel < -1) {
      pyroSequenceStep = 4;
    } else {
      Serial.println("FIRING PYRO 3!");
      digitalWrite(PYRO_POP, HIGH);
      pyroStartTime = currentTime;
      pyroSequenceStep = 3;
    }
  }
  else if (pyroSequenceStep == 3 && (currentTime - pyroStartTime >= 5000)) {
    digitalWrite(PYRO_POP, LOW);
    pyroSequenceStep = 4; 
  }

  if (pyroSequenceStep == 4) {
    disableAllActuators();
    pyroFiring = false;
    pyroSequenceStep = 0;
    Serial.println("Pyro sequence complete, actuators disabled, transitioning to DESCENT");
    return true; // One of the pyros worked, so return true to trigger state transition
  }

  return false;
   
}

void disableAllActuators() {
  digitalWrite(THRUSTER_LEFT, LOW);
  digitalWrite(THRUSTER_RIGHT, LOW);
  digitalWrite(PYRO_DETATCH_1, LOW);
  digitalWrite(PYRO_DETATCH_2, LOW);
  digitalWrite(PYRO_POP, LOW);
  
  leftThrusterOn = false;
  rightThrusterOn = false;
}

bool isPyroFiring() {
  return pyroFiring;
}

bool getLeftThrusterState() {
  return leftThrusterOn;
}

bool getRightThrusterState() {
  return rightThrusterOn;
}

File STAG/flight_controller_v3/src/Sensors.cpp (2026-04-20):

#include "Sensors.h"

Adafruit_BMP3XX bmp;
Adafruit_BNO055 bno = Adafruit_BNO055();

float baseAlt; // Base altitude for relative measurements

void initSensors()
{
    Wire.begin();
    delay(500); 
    Serial.println("Waiting for sensors to initialize...");
    // Initialize barometer
    if (!bmp.begin_I2C(0x77))
    {
        Serial.println("Could not find a valid BMP3XX sensor, check wiring!");
        while (1)
            ;
    }
    delay(500); 
    Serial.println("Waiting for sensors to initialize...");

    // Initialize IMU
    if (!bno.begin())
    {
        Serial.println("No BNO055 detected, check wiring!");
        while (1)
            ;
    }

    delay(500); 
    Serial.println("Waiting for sensors to initialize...");

    bmp.setTemperatureOversampling(BMP3_OVERSAMPLING_8X);
    bmp.setPressureOversampling(BMP3_OVERSAMPLING_4X);
    bmp.setIIRFilterCoeff(BMP3_IIR_FILTER_COEFF_3);
    bmp.setOutputDataRate(BMP3_ODR_50_HZ);

    bmp.performReading();
    bmp.performReading();
    bmp.performReading();
    baseAlt = bmp.readAltitude(SEALEVELPRESSURE_HPA);

    bno.setExtCrystalUse(true); // Better accuracy

    Serial.println("Sensors initialized");

}

void readBarometer(float &temperature, float &pressure, float &altitude)
{
#ifdef HIL_MODE
    static float lastAltitude = 0.0;
   if (Serial.available() > 0)
    {
        String line = Serial.readStringUntil('\n');
        line.trim();
        
        // 1. Check that the string actually has data after "ALT:"
        if (line.startsWith("ALT:") && line.length() > 4)
        {
            float parsedAlt = line.substring(4).toFloat();
            
            // Rate Limiter
            if (lastAltitude == 0.0 || abs(parsedAlt - lastAltitude) < 10.0)
            {
                lastAltitude = parsedAlt;
            }
        }
    }
    altitude = lastAltitude;
    temperature = 20.0;
    pressure = 1013.25;
#else
    if (bmp.performReading())
    {
        temperature = bmp.temperature;
        pressure = bmp.pressure;
        altitude = bmp.readAltitude(SEALEVELPRESSURE_HPA) - baseAlt; // Relative altitude
    }
    else
    {
        Serial.println("Failed to perform reading from BMP3XX");
    }
#endif
}

void readIMU(float &roll, float &pitch, float &heading, float &vertical_accel)
{
    sensors_event_t event;
    bno.getEvent(&event);

    // Also read linear acceleration for GNC activation check
    imu::Vector<3> accel = bno.getVector(Adafruit_BNO055::VECTOR_LINEARACCEL);

    vertical_accel = accel.z();  // remove "float" to avoid shadowing

    roll = event.orientation.y;
    pitch = event.orientation.z;
    heading = event.orientation.x;
}

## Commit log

2025-09-30 transfered GNC Polaris files to this github
    [PID_boiled_1.csv, PID_boiled_2.csv, PID_boiled_3.csv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]
2025-11-06 Squashed commit of the following:
    commit 1dba94bd67e0e9e9782bb02605f0dda92fad6f34
    Author: Shashank Aritottam Namboodiri <snambood@purdue.edu>
    Date: Wed Nov 5 19:39:24 2025 -0500
    changing the file format for new test log
    commit 669e1e16f98d1be8ff5be52fef48e35af7ce78f7
    Author: Shashank Aritottam Namboodiri <snambood@purdue.edu>
    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
    [3-31-25_low-pass-derivative_test.csv, log_20000101_000005.csv, log_20000101_000006.csv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]
2025-11-13 added test scripts and files
    [test1.csv, test2.csv, test3.csv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]
2026-02-16 added PCB
    [4682 Micro SD Breakout.step, 4816 BMP390 QT.step, 5708 CAN Pal.step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]
2026-03-04 added newest version (4.1) of pcb
    [4682 Micro SD Breakout.step, 4816 BMP390 QT.step, 5708 CAN Pal.step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]
2026-03-04 updated PCB
    [polaris4.1.kicad_pcb, polaris4.1.kicad_sch]
2026-03-13 flight controller firmware v2
    [4682 Micro SD Breakout.step, 4816 BMP390 QT.step, 5708 CAN Pal.step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]
